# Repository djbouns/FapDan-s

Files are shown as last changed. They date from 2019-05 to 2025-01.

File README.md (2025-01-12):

# FapDan-s V2

## Le filtre à papier 100% DIY pour l'aquariophilie

Bonjour,

Ce filtre a papier 3D a été développé par Dan's avec ma colaboration.

#### Soutenir se projet par un DON, c'est nous permettre de vous proposez de nouveau projet, des évolutions et cela, toujours GRATUITEMENT.

 

### Pour la réalisation, il vous faudras :
- Du PETG : https://amzn.to/428bnMW,
  https://amzn.to/3FKoPeO,
  https://amzn.to/4ja6JEo,
  https://amzn.to/4gOcTZ9,
  https://amzn.to/3DQryoc
- Motoréducteur 3,5 ou 7 RPM en 12V : https://amzn.to/3Ugyaio
- Vis inox M3 *10mm : https://amzn.to/3wchOvQ
- Vis inox M3 *5mm : https://amzn.to/357KsCc
- Flotteur : https://amzn.to/4haH9gu
- Alimentation 12V 1A ou 2A : https://amzn.to/3Pyc8aK,
  https://amzn.to/4h7XCCi,
  https://amzn.to/2TbOJC2
- Arduino nano : https://amzn.to/40f2hLI (original),
  https://amzn.to/3Pw0kWr,
  https://amzn.to/3wakk5R,
  https://amzn.to/40f2kXU
- Shield arduino nano : https://amzn.to/3g7mm0U
- Relais : https://amzn.to/3vgb3ba,
  https://amzn.to/42dsw83
- bouton instantané : https://amzn.to/4gLURa3,
  https://amzn.to/3BT9tFx,
  https://amzn.to/4jeQeXx,
  https://amzn.to/4hcpkh8
- Lot leds + resistance : https://amzn.to/3C5HD8S
+ Ou
- Led seul : https://amzn.to/40fuBOa,
  https://amzn.to/40ag9Hq,
  https://amzn.to/3PvMlzX,
  https://amzn.to/3C55mpJ
- Resistance seul : https://amzn.to/42sKOT9,
  https://amzn.to/42f93UJ,
  https://amzn.to/3PssS3c,
  https://amzn.to/3PCEsbP

#### Fonctions :
> Temporisation du flotteur pour ne pas avoir de déclenchement du motoréducteur trop minime a répétition.  
> Led verte = système actif  
> Led rouge = système inactif  
> Le boitier active/désactive automatiquement le moteur en fonction du flotteur.  
> A la fin d'un rouleaux, cela génère des déclenchement répétitif du flotteur ou un trop long déclenchement, le boitier coupe le moteur / met le système inactif  
> Led verte allumé + flash de la led rouge = déclenchement répétitif survenu moins de 15 seconde après rotation du moteur ( le nombre de flash rouge correspondant au nombre de déclenchement intempestif consécutif, MAX 3 avant que le système soit mis inactif)  
> un appui sur le bouton supérieur a 1.5 seconde remet le système actif et met en marche le moteur. Lorsque vous relâcher le bouton, si le flotteur est bas, le moteur est coupé. Si le flotteur en haut, le moteur continue de tourner jusqu'au moment ou le flotteur soit en position basse.  

### tuto complet du montage :
- http://www.recifal-france.fr/fabrication-du-fapdan-s-v2-filtre-a-papier-de-a-a-z-t37701.html
### Vidéos de l'assemblage :
- https://www.youtube.com/watch?v=h5cT0cDPbm4
- https://www.youtube.com/watch?v=h5cT0cDPbm4
- https://www.youtube.com/shorts/dXKUHesqrk0

GRAND MERCI a Dan's pour ce filtre 3D

## Vous êtes FAN de DIY ? ... 
# Venez découvrir l'AQUABOUNS, 
## l'automate de gestion pour aquarium récifal
# www.aquabouns.fr

Téléchargement : https://github.com/djbouns

A bientôt

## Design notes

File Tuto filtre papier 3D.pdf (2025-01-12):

Bienvenu dans ce nouveau tuto DIY sur la fabrication du filtre à papier :

## Le FapDan's V2

Il y a plusieurs semaines, les plans 3D d'un filtre à papier ont été mis à disposition gratuitement sur un groupe Facebook, DIY RECIFAL 3D, (https://www.facebook.com/groups/318150642243111/) par Dan's (http://www.recifal-france.fr/membre8455.html)

Déjà très bien conçu au départ, j'ai pris contact avec Dan's en vue d'une collaboration pour améliorer encore plus ce filtre.
Après plusieurs semaines de test et d'évolution, nous pouvons dire aujourd'hui que le résultat est satisfaisant et que nous pouvons le partager.

Nous le mettons à dispositions cette nouvelle version, toujours GRATUITEMENT, accompagner de ce TUTO.

## Vous pouvez télécharger les plan 3d et le code ICI (https://github.com/djbouns/FapDan-s)

Ce tuto va se décomposer en plusieurs partie :
I. Cout
II. | Impression 3D des pièces
III. | Montage du filtre
IV. | Montage du boitier de commande (facultatif)
V. Fonctionnement du boitier de commande (facultatif)
VI. Trucs et astuces

Voici des liens pour le matériel nécessaire à la réalisation du FapDan’s :

| Du PETG : https://amzn.to/428bnMW , https://amzn.to/3FKoPeO ,
| https://amzn.to/4ja6JEo , https://amzn.to/4gOcTZ9 , https://amzn.to/3DQryoc
| Motoréducteur 3,5 RPM en 12V : https://amzn.to/3Ugyaio
| Vis inox M3 *10mm : https://amzn.to/3wchOvQ
| Vis inox M3 *5mm : https://amzn.to/357KsCc
| Flotteur : https://amzn.to/4haH9gu
| Alimentation 12V 1A ou 2A : https://amzn.to/3Pyc8aK , https://amzn.to/4h7XCCi ,
| https://amzn.to/2TbOJC2
| Arduino nano : https://amzn.to/40f2hLI (original), https://amzn.to/3Pw0kWr ,
| https://amzn.to/3wakk5R , https://amzn.to/40f2kXU
| Bouclier Arduino Nano : https://amzn.to/3g7mm0U
| Relais : https://amzn.to/3vgb3ba , https://amzn.to/42dsw83
| Bouton instantané : https://amzn.to/4gLURa3 , https://amzn.to/3BT9tFx ,
| https://amzn.to/4jeQeXx , https://amzn.to/4hcpkh8
| Lot de leds + résistances : https://amzn.to/3C5HD8S
| Led seul : https://amzn.to/40fuBOa , https://amzn.to/40ag9Hq ,
| https://amzn.to/3PvMlzX , https://amzn.to/3C55mpJ
| Résistance seule : https://amzn.to/42sKOT9 , https://amzn.to/42f93UJ ,
| https://amzn.to/3PssS3c , https://amzn.to/3PCEsbP

!!! ATTENTION !!!
Je ne suis pas électricien ni électronicien.
Ce qui suit n'est qu'un simple partage d'expérience. Toute connexion/interface avec des tensions dangereuses ne doit se faire que par du personnel qualifié et selon les normes en vigueur afin d'éviter tout risque d'accident ou d'incendie.
Djbouns décline toute responsabilité quant aux dommages directs ou indirects qui pourraient être causés.
I. Cout

Le cout de fabrication du filtre dépendra essentiellement du « petit matériel » déjà en votre possession (Leds, résistances, …)
Entre l’impression3D (environ 1kg de filament) et le reste de composant, le cout de fabrication est d’environ :
40€ / 70€ pour la version sans contrôleur
Et 65€ / 100€ Pour la version avec contrôleur

II. Impression 3D des pièces

Vous aurez besoin :
- Une imprimante 3D
- Une bobine de filament PETG

Je ne vais pas vous expliquer ici comment imprimer en 3D, d'autres tutoriels le ferons bien mieux que moi.
Je vous conseille d'avoir bien pris votre machine en main avant de vous lancer dans ces longues heures d'impressions.

Pour le filtre à papier et pour tout ce qui est en contact avec mon aquarium, j'utilise du filament en PETG car il résiste à l'eau et est homologué pour le contact alimentaire. En plus, le PETG est assez facile imprimer, lit a 80° et buse a 240° (chez moi)

Une fois toutes les pièces imprimées, vous pouvez passer à l’assemblage.

III. Assemblage du filtre

Vous aurez besoin :
- Des pièces imprimées en 3D
- D'un flotteur
- D'un motoréducteur
- Une alimentation 12Vdc (si vous n'utilisez pas le boitier de commande)

Dans un premier temps, il faut souder 2 fils à votre moteur.
Prévoyez une longueur plus on moins importante en fonction de votre montage (boitier de contrôle ou pas, distance de votre alimentation)

Ensuite, mise en place du moteur dans son logement :

Fixation avec les vis M3x10 INOX :

Mise en place du capot moteur :

Mise en place du rouleau moteur (il faut forcer un peu) :

Mise en place du cache (doit pouvoir se retirer pour mettre en place le papier) :

Pour recapituler ce montage, une petite vidéo

Regarder sur youtube.com (https://youtu.be/QKYtz0qKcmg)

On passe au montage complet du filtre : Regarder sur youtube.com (https://youtu.be/h5cT0cDPbm4)

Þ Si vous voulez réaliser le filtre à papier avec son boitier de commande, passer à l'étape III.

Þ Si vous ne souhaitez pas utiliser le boitier de commande, prenez connaissance des défauts que ce montage simplifier comporte :
- Pas de déclenchement manuel possible (il faut soulever le flotteur si on veut activer le moteur).
- Pas d'arrêt du moteur en fin de rouleau (soit le moteur va tirer jusque à ce que le papier se décolle du carton, soit le moteur va forcer et risque d'être endommager).
- Pas de temporisation (donc des micros déclenchement) dans le cas ou votre descente n'est pas régulière (syphon).

Pour le montage sans boitier de contrôle, Il va falloir brancher le flotteur, le motoréducteur et l'alimentation.
L'intérieur du compartiment moteur doit pouvoir vous permettre de faire les branchements pour qu’il soir ptoteger.
Si l'endroit vous parait trop petit, vous prouver aussi faire les connections à l’intérieur d’une petite boite de dérivation que vous installerez plus loin (protéger de l'eau)
Quoi qu'il en soit, les connexions à faire sont les mêmes, voici le schéma :

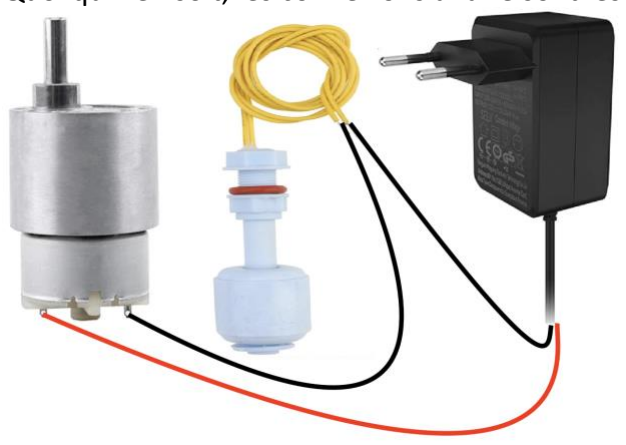
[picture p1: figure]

Avant de tout mettre en place, vérifier bien que le moteur tourne dans le bon sens. Dans le cas contraire inverser la polarité du moteur.
Maintenant, votre filtre est parfaitement fonctionnel !

IV. Montage du boitier de commande (facultatif)

Vous aurez besoin :

- Le boitier 3d
- D’un Arduino nano
- D’un relais ou mosfet
- D’une alimentation 12Vdc
- D’une LED verte + une LED rouge
- Deux résistances 1/2W, 1K
- D’un bouton instantané 12mm
- D’un domino / Wago, https://amzn.to/3C6jMpO, https://amzn.to/428foRC
- De gaine thermo rétractable, https://amzn.to/4gOgLJz, https://amzn.to/4gPaFJc
- De petits câble, https://amzn.to/40xrzq8, https://amzn.to/3PygcYG

Commencer par souder les LED aux résistances 1k et aux fils.
Si vous avez des doutes sur la façon de faire vous pouvez aller voir ici (https://www.interface-z.com/conseil/montage-led.php)

Souder 2 fils sur votre bouton

Installer les Leds et le bouton dans le boitier 3D :

Maintenez les Leds avec de la colle à chaud.

Fixer votre Shield et le relais ou Mosfet sur la plaque de la boite 3D :

Montage avec Relais | Montage avec Mosfet

Le Mosfet est préférable au relais car il ne comporte pas de composant en mouvement. De plus, si vous êtes susceptible coté bruit, vous n'aurez pas les clics du relais)
montage avec relais.

Afin de fiabiliser le montage, je vous conseille de souder les câbles sur les pin plutôt que d'utiliser des connexion femelle emboitable.

La suite du tuto sera faite en utilisant le Mosfet ( les connections du relais coté Arduino sont identique que le Mosfet)

Fixer 2 fils rouge sur un côté d’un domino.
Un de ces fil va jusqu’au Vin du Shield.
L’autre jusqu’au Vin du Mosfet.
Sur un autre domino fixer 2 fils noir:
Un de ces fil va jusqu’au GND du Shield (en même temps connecter sur le pin GND du Shield le GND le GND de votre alimentation 12V.
L’autre fil va jusqu’au GND du Mosfet.

Faite passer les fils de votre flotteur dans le boitier puis souder un des fils du flotteur avec un des fils du bouton + les GND des deux Leds (donc 4 fils reliés)

Connecter ces 4 fils sur le GND du Shield.
Connecter le positif de la LED verte (pin long) au Shield : D2 Connecter le positif de la LED rouge (pin long) au Shield : D3 Connecter le fil restant du flotteur au Shield : D4
Connecter le fil restant du bouton au Shield : D5

Votre montage doit ressembler à ça :

Connecter le fil venant du pin IN du Mosfet au Shield : A0
Passer le câble de votre alimentation dans le boitier puis connecter le positif au domino avec les fils rouges et le négatif sur le domino avec les fils noir (vérifier bien la polarité)
Votre montage doit ressembler à cela :

Il faut maintenant installer le programme dans votre Arduino nano.
Télécharger et installer l'IDE Arduino (https://www.arduino.cc/en/Main/Software)

Connecter votre Arduino nano en USB, le driver devrait s'installer automatiquement. Si ce n'est pas le cas, le driver se trouve dans C:\Program Files\Arduino\drivers Ouvrer "filtre_papier.ino" dans l'IDE Arduino
Aller dans outils / type de carte et sélectionner Arduino nano
Dans outils / port, sélectionner le port de votre Arduino (exemple, COM1) Vous pouvez cliquer sur téléverser le programme.

Si le téléversement est très long et fini par une erreur, il est possible que votre carte ais un "vieux" bootloader. Dans ce cas, faite cette modification, outils / processeur et sélectionner ATmega328p (old bootloader) puis recommencer le téléversement

Votre Arduino est programmé.

Installer le sur le Shield

Maintenant, votre filtre est parfaitement fonctionnel !

Avant de le mettre en place, vérifier bien que le moteur tourne dans le bon sens de rotation. Dans le cas contraire inverser la polarité du moteur.

Fermer le boitier et mettez les 4 vis sur les côtés

V. Fonctionnement du boitier de commande (facultatif)
1. LED verte = système actif
2. LED rouge = système inactif
3. Le boitier active/désactive automatiquement le moteur en fonction du flotteur.
4. Temporisation du flotteur pour ne pas avoir de déclenchement du motoréducteur trop minime à répétition.
5. A la fin d’un rouleau, cela génère des déclenchements répétitifs du flotteur ou un trop long déclenchement, le boitier coupe le moteur / met le système inactif.
6. LED verte allumé + flash de la LED rouge = déclenchement répétitif survenu moins de 15 secondes après rotation du moteur (le nombre de flash rouge correspondant au nombre de déclenchement intempestif consécutif, MAX 3 avant que le système soit mis inactif)
7. Un appui sur le bouton supérieur à 1.5 seconde remet le système actif et met en marche le moteur. Lorsque vous relâcher le bouton, si le flotteur est bas, le moteur est coupé. Si le flotteur en haut, le moteur continue de tourner jusqu'au moment où le flotteur soit en position basse.

VI. Trucs et astuces

1. Déclenchement du flotteur :
Nos bac sont tous diffèrent et l'eau qui arrive dans le filtre peut se comporter de façon totalement différente.
Cela peut générer des réactions "bizarres" du flotteur, déclenchement saccader (siphon de la descente), pas de déclenchement (l'eau en rotation retombe par-dessus le flotteur, cette force empêche le flotteur de monter).
Pour contrer cela plusieurs solutions qu'ils vous faudra tester et peut être combiner.
- Orienter le tuyau d'arrivée d'eau du filtre de différente façon, vers le haut, le bas etc.
- Utiliser une des 2 protections de flotteur fournie dans les plan 3D.
(exemple chez moi sans protection flotteur, tuyau vers le haut = flotteur ne se déclenchait pas. Solution, tuyau vers le bas + protection flotteur)
2. Les consommable :
Au prix des rouleaux de papier et pour notre planète, sa fait chi** de les jeter.
Le papier peut être lavé !
- Tremper le 24h dans l'eau de javel puis un tour a la machine à laver à froid sans autre produit, on fait sécher et c’est reparti.
- Le papier est difficile à faire tenir sur le rouleau moteur et le rouleau papier lavé. Pour solutionner le problème vous aller avoir besoin de fil et d'une aiguille.
Prenez une extrémité de papier et replier la d'un centimètre 3 fois.
Ensuite vous faite une couture sur le milieu de ce pli sur toute la longueur :

Faite cela sur les 2 extrémités du papier.
- Pour fixer le papier sur les rouleaux il suffit de glisser la couture dans la fente des rouleaux. Le "Rouleau papier lave V2.STL" est spécialement conçu pour que vous puissiez enrouler vos papiers laver dessus.

- Enrouler le papier sur le rouleau.
Il est inutile de serrer fort le papier sur le rouleau !
Si le rouleau de papier propre est trop serré, il oppose une résistance et le moteur va serrer le papier en l'enroulant coté sale. Cela va rendre votre changement de rouleau très difficile).
3. Changement de rouleau :
- Lorsque votre rouleau est fini, retirez le rouleau vide et débloquer le papier. Fixer le nouveau papier a l'ancien avec une aiguille ou un cure-dent puis tirer sur l'ancien papier coté moteur jusqu'à ce que le nouveau papier soit du côté moteur.
- Débloquer le rouleau du moteur, enlever le cache de côté et retirer l'ancien papier fixer le nouveau papier

J’espère que ce tuto vous a été utile, Bon montage à tous Et un GRAND MERCI à Dan's

## WWW.AQUABOUNS.FR

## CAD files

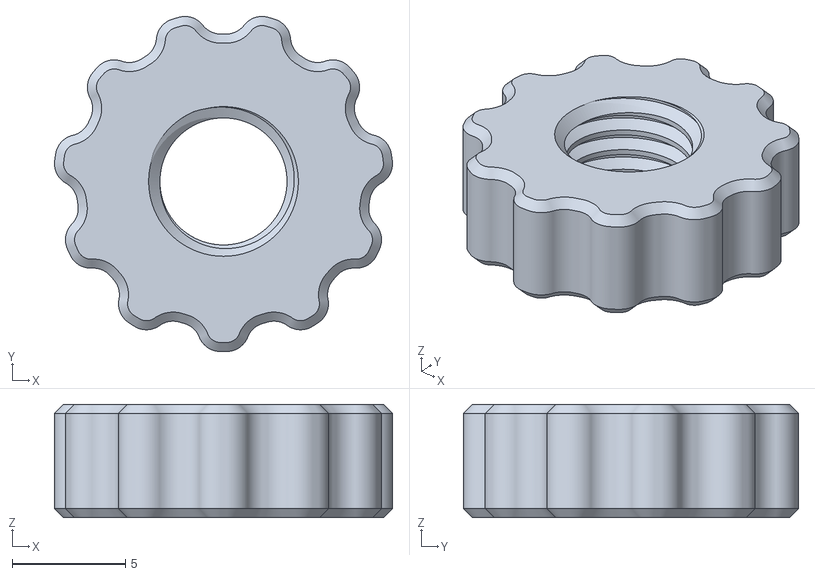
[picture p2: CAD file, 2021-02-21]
Plan 3D/Ecrou assemblage M6.STL
14.9 x 14.8 x 5.00

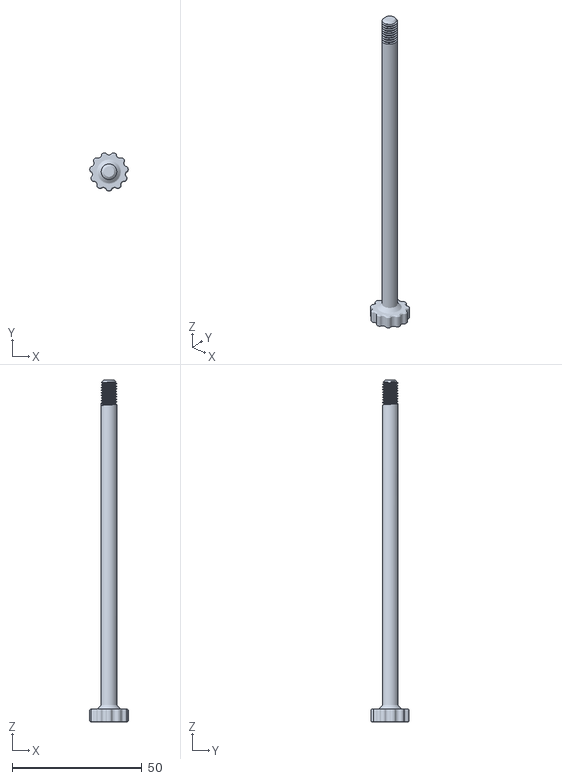
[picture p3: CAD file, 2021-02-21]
Plan 3D/Vis assemblage M6.STL
14.9 x 14.8 x 132.0

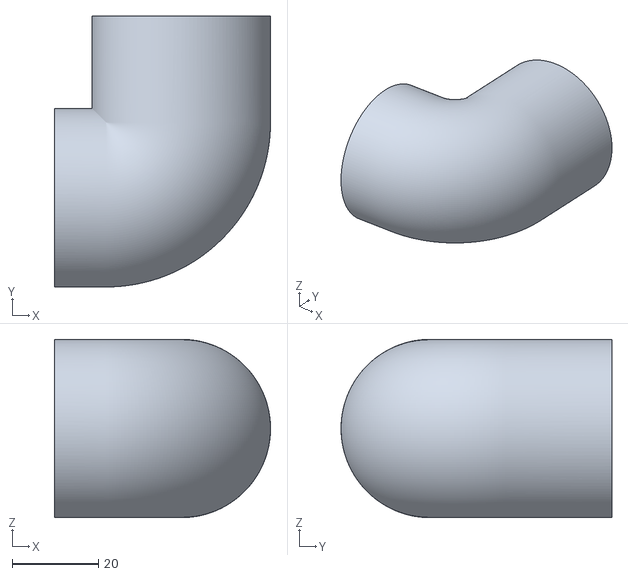
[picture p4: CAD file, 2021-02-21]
Plan 3D/Coude 90 V2 (32mm).STL
50.0 x 62.7 x 41.3

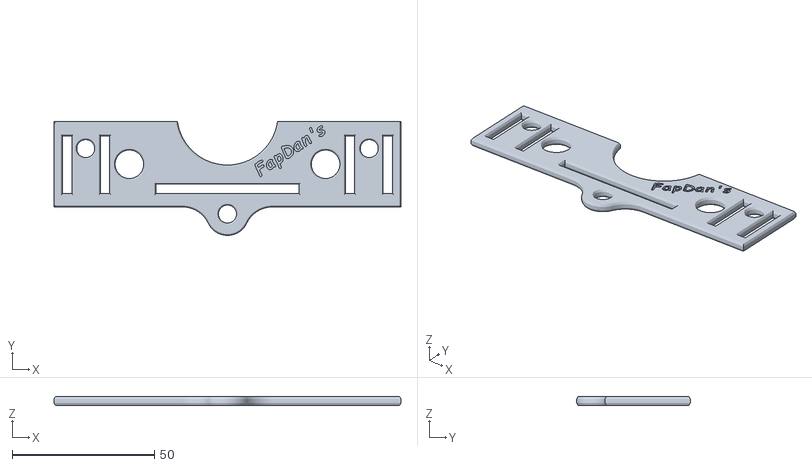
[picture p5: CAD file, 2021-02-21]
Plan 3D/Piece C.STL
122.0 x 40.0 x 3.00

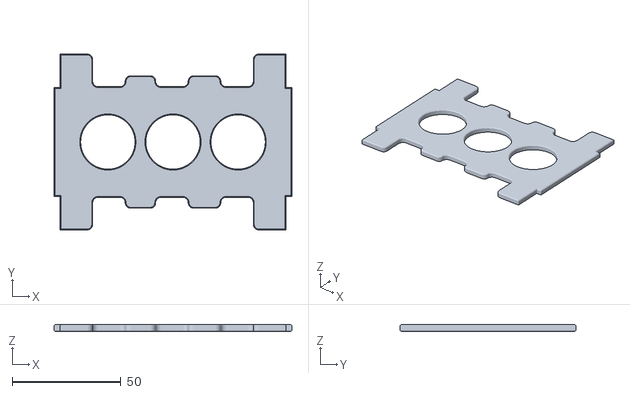
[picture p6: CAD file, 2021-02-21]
Plan 3D/Grille B.STL
109.6 x 81.0 x 3.00

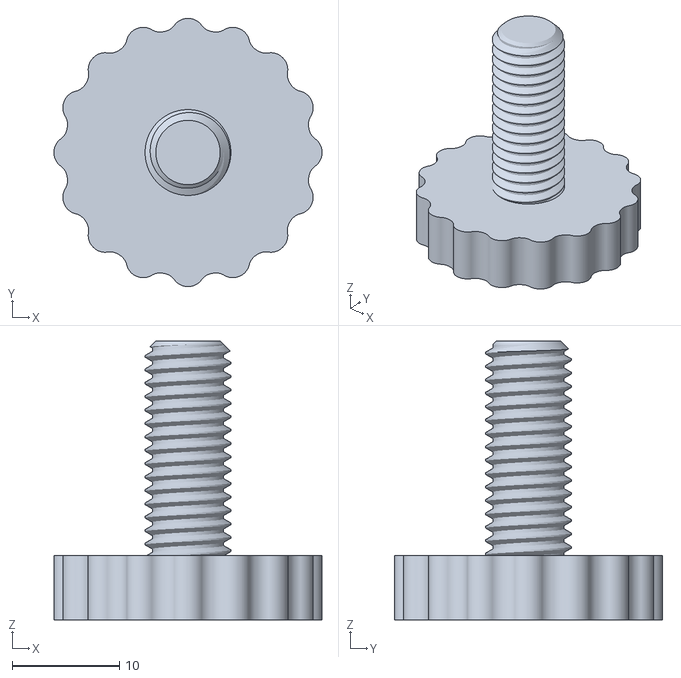
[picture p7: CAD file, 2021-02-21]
Plan 3D/Vis rouleaux M8.STL
25.0 x 25.0 x 26.0

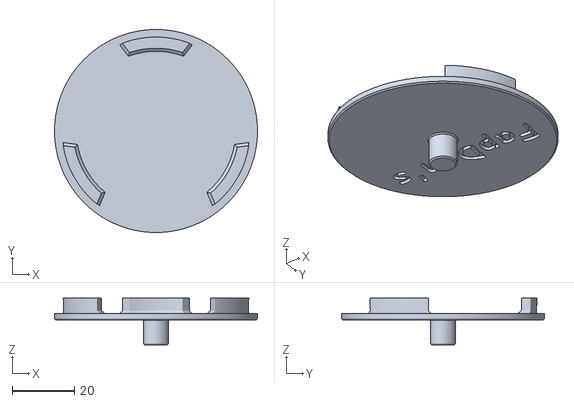
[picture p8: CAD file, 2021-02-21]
Plan 3D/Bouchon rouleau moteur V2.STL
65.0 x 65.0 x 15.0

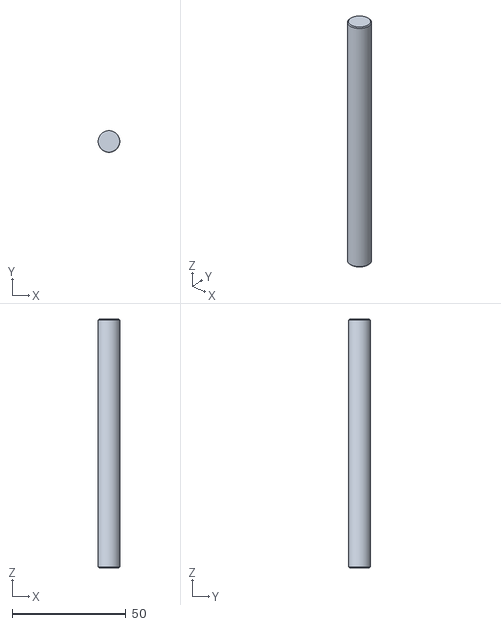
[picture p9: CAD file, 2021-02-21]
Plan 3D/Rouleau retour.STL
9.53 x 9.53 x 109.5

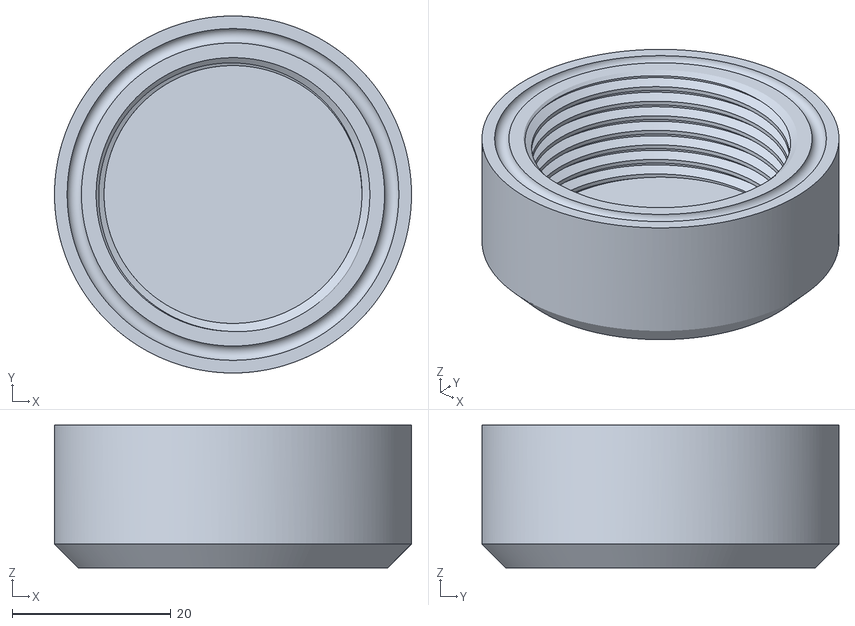
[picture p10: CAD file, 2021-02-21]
Plan 3D/Bouchon.STL
45.0 x 45.0 x 18.0

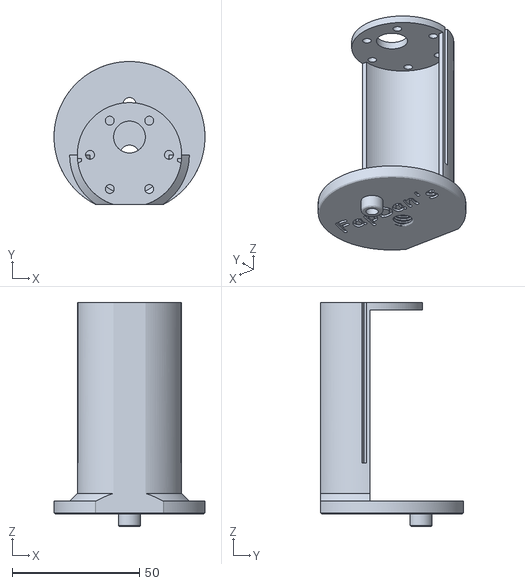
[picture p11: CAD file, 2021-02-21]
Plan 3D/Support moteur.STL
59.3 x 56.1 x 88.0

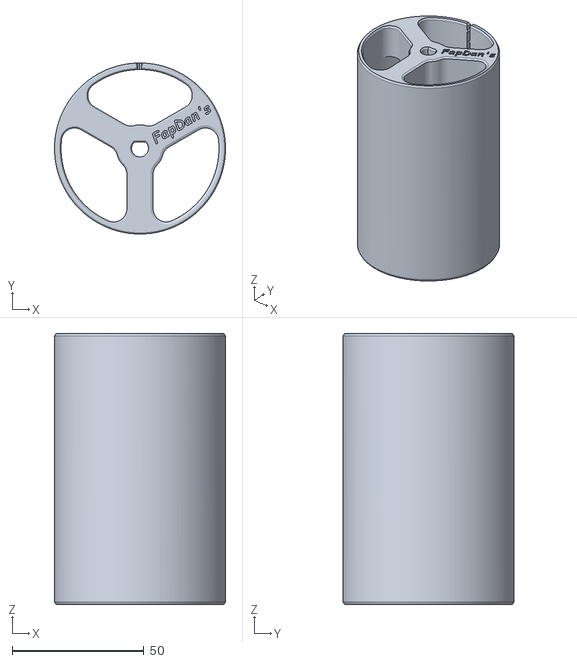
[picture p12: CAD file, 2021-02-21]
Plan 3D/Rouleau moteur V3.STL
65.0 x 65.0 x 103.0

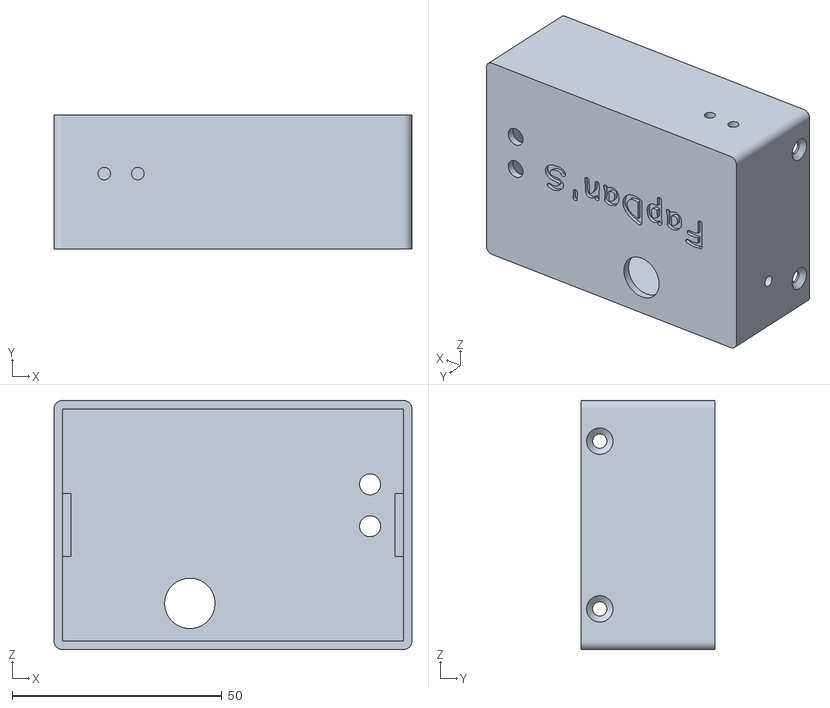
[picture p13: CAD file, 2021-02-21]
Plan 3D/Couvercle controleur.STL
85.4 x 32.0 x 59.4

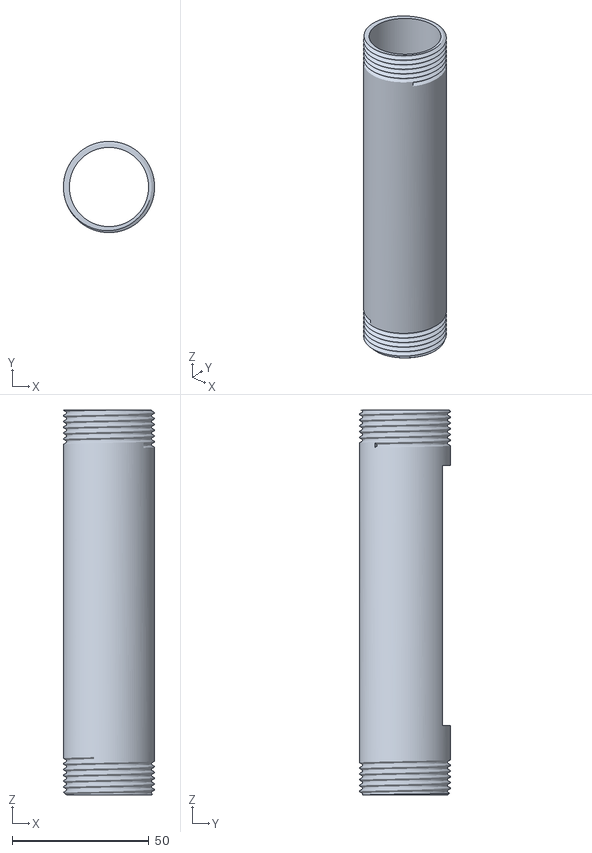
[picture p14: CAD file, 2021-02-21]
Plan 3D/Tuyau V2.STL
33.4 x 33.4 x 141.0

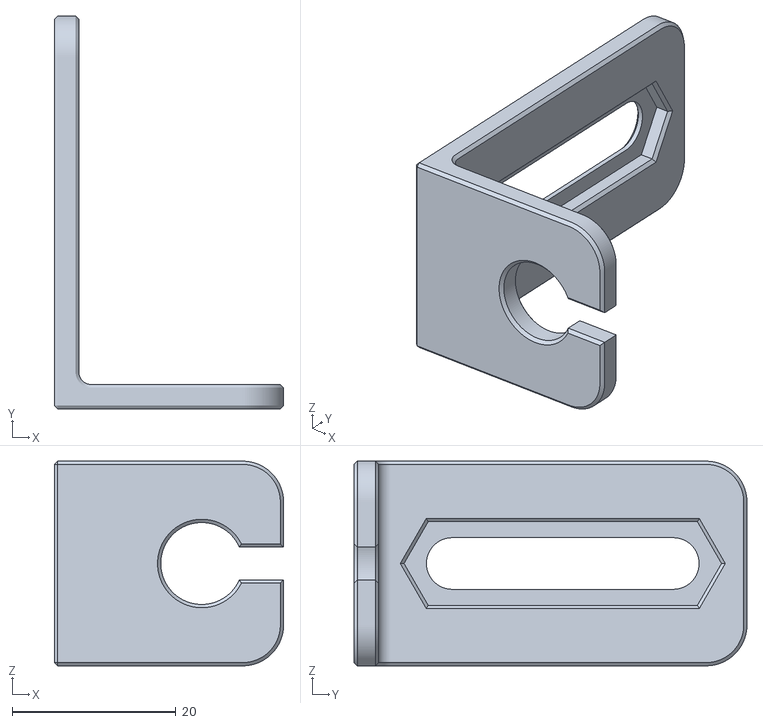
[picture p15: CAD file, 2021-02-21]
Plan 3D/Support niveau V2.STL
28.0 x 48.0 x 25.0

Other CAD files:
Plan 3D/Coude 90 V2 (USA).STL
Plan 3D/Piece B.STL
Plan 3D/Piece D haut auto V3.STL
Plan 3D/Base controleur.STL
Plan 3D/Centre rouleau papier lave V2.STL
Plan 3D/Couvercle moteur.STL
Plan 3D/Ecrou support capteur niveau M6.STL
Plan 3D/Grille A.STL
Plan 3D/Piece A bas.STL
Plan 3D/Piece A haut auto V2.STL
Plan 3D/Protecteur flotteur V2.STL
Plan 3D/Protecteur flotteur.STL
Plan 3D/Rouleau papier lave V2.STL
Plan 3D/Rouleau papier neuf.STL
Plan 3D/Support.STL
Plan 3D/Vis rouleaux M6.STL
Plan 3D/Vis support capteur niveau M6.STL

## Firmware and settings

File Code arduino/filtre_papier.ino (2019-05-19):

/********************************************************************************************************************************************************************************************************
****                                                                                          FapDan's v2.0                                                                                          ****
****                                                                                       écrit par Djbouns                                                                                         ****
****                                                   Gestion du FapDan's, filtre a papier réalisé en impression 3D avec les plans dessinés par Dan's                                               ****
****                                                                                           18/05/2019                                                                                            ****
********************************************************************************************************************************************************************************************************/

/* FapDan's, Gestion du filtre a papier réalisé en impression 3D avec les plans dessinés par Dan's
   Copyright (C) 2019 par dj bouns

   Ce programme est un logiciel libre: vous pouvez le redistribuer
   et/ou le modifier selon les termes de la "GNU General Public
   License", tels que publiés par la "Free Software Foundation"; soit
   la version 2 de cette licence ou (à votre choix) toute version
   ultérieure.

   Ce programme est distribué dans l'espoir qu'il sera utile, mais
   SANS AUCUNE GARANTIE, ni explicite ni implicite; sans même les
   garanties de commercialisation ou d'adaptation dans un but spécifique.

   Se référer à la "GNU General Public License" pour plus de détails.
   Vous la trouverez dans l'onglet GNU_General_Public_License.h

   Vous devriez avoir reçu une copie de la "GNU General Public License"
   en même temps que ce programme; sinon, écrivez a la "Free Software
   Foundation, Inc., 675 Mass Ave, Cambridge, MA 02139, USA".*/

#include <avr/wdt.h>

//$$$$$$$$$$$$$$$$$$$$$$$$$$$$$$$$$$$$$$$$$$$$$$$$$$$$$$$$$$$$$$$$$$$$$$$$$$$$$$$$$$$$$$$$$$$ Déclarations $$$$$$$$$$$$$$$$$$$$$$$$$$$$$$$$$$$$$$$$$$$$$$$$$$$$$$$$$$$$$$$$$$$$$$$$$$$$$$$$$$$$$$$$$$$
const byte relais = A0; // pin du relais
const byte ledVerte = 2; // pin de la led verte
const byte ledRouge = 3; // pin de la led rouge
const byte flotteur = 4; // pin du flotteur
const byte bouton = 5; // pin du bouton
const uint16_t delaisFlotteurHaut = 500; // delais avant mise en route du moteur 1/2 sec
const uint16_t delaismoteurOn = 1000; // delais avant mise en route du moteur 1/2 sec
const uint16_t delaisMaxFlotteurHaut = delaisFlotteurHaut + 3500; // delais max avant de stoper moteur 3.5 sec + delais flotteur haut
uint32_t compteurFlotteur = 0; // pour stocker le compteur flotteur
boolean compteurFlotteurOn = false; // pour mettre on off le compteur flotteur
boolean enFonction = true; // pour mettre on off le moteur
const uint16_t delaisBouton = 1500; // delais dactivation du bouton 1.5 sec
const uint16_t delaisFinDeRlx = 15000; // delais durant le quel les declanchement son comptés , pour detécter la fin de rouleau 15 sec
const uint8_t declenchementMaxFinDeRlx = 3; // 3 declenchements
uint8_t declenchementRlx =  0; // pour stocker les declenchements
uint32_t compteurDeclenchement = 0; // pour stocker le compteur declenchement
uint32_t compteurBouton = 0; // pour stocker le compteur bouton
boolean compteurBoutonOn = false; // pour mettre on off le compteur bouton

//$$$$$$$$$$$$$$$$$$$$$$$$$$$$$$$$$$$$$$$$$$$$$$$$$$$$$$$$$$$$$$$$$$$$$$$$$$$$$$$$$$$$$$$$$$$ Debug $$$$$$$$$$$$$$$$$$$$$$$$$$$$$$$$$$$$$$$$$$$$$$$$$$$$$$$$$$$$$$$$$$$$$$$$$$$$$$$$$$$$$$$$$$$
//#define DEBUG // à commenter pour enlever le debug
#ifdef DEBUG
#define DebugPrintLN(x)  {Serial.println(x);}
#else
#define DebugPrintLN(x)
#endif

//$$$$$$$$$$$$$$$$$$$$$$$$$$$$$$$$$$$$$$$$$$$$$$$$$$$$$$$$$$$$$$$$$$$$$$$$$$$$$$$$$$$$$$$$$$$ Setup $$$$$$$$$$$$$$$$$$$$$$$$$$$$$$$$$$$$$$$$$$$$$$$$$$$$$$$$$$$$$$$$$$$$$$$$$$$$$$$$$$$$$$$$$$
void setup() {
  Serial.begin(9600);
  pinMode(ledRouge, OUTPUT); // configure le pin en sortie
  pinMode(ledVerte, OUTPUT); // configure le pin en sortie
  pinMode(relais, OUTPUT); // configure le pin en sortie
  pinMode(flotteur, INPUT_PULLUP); // configure le pin en entre en mode pullup
  pinMode(bouton, INPUT_PULLUP); // configure le pin en entre en mode pullup
  digitalWrite(ledVerte, HIGH); // led verte on
  wdt_enable(WDTO_8S); // Si plus de remise a zero du compteur "reboot" (fait dans le loop) au bout de 8 secondes = bug de l'arduino = reboot automatique !
}

//$$$$$$$$$$$$$$$$$$$$$$$$$$$$$$$$$$$$$$$$$$$$$$$$$$$$$$$$$$$$$$$$$$$$$$$$$$$$$$$$$$$$$$$$$$$ Loop $$$$$$$$$$$$$$$$$$$$$$$$$$$$$$$$$$$$$$$$$$$$$$$$$$$$$$$$$$$$$$$$$$$$$$$$$$$$$$$$$$$$$$$$$$$
void loop() {
  if (digitalRead (bouton) == LOW) { // si bouton active
    DebugPrintLN("bouton appuyer"); // debug
    if (compteurBoutonOn == false) { // si compteur bouton off
      compteurBoutonOn = true; // compteur bouton on
      compteurBouton = millis(); // stock le timer
      DebugPrintLN("démarre le compteur du bouton"); // debug
    }
    if (delaisBouton < (millis() - compteurBouton)) { // si bouton active plus longtemps que delaisBouton
      enFonction = true; // moteur on
      digitalWrite(ledVerte, HIGH); // led verte on
      digitalWrite(ledRouge, LOW); // led rouge off
      digitalWrite(relais, HIGH); // relais on = moteur on
      declenchementRlx = 0; // remet le compteur de declenchement a zero
      compteurFlotteurOn = false; // remet le compteur flotteur en OFF
      DebugPrintLN("réactive le fonctionnement, LED verte et rouleau ON manuelement"); // debug
      while (digitalRead (flotteur) == LOW) { // boucle temps que le flotteur n'est pas bas
      }
    }
  }
  else { // si bouton pas active
    compteurBoutonOn = false; // compteur off
    if (enFonction == true) { // si en fonction
      DebugPrintLN("systeme activé, LED verte"); // debug
      if (digitalRead (flotteur) == LOW) { // si flotteur haut
        DebugPrintLN("flotteur Haut"); // debug
        if (compteurFlotteurOn == false) { // si compteur off
          compteurFlotteurOn = true; // on met le compteur on
          compteurFlotteur = millis(); // stock le timer      
          DebugPrintLN("démarre le compteur de flotteur haut"); // debug
        }
        if (millis() - compteurDeclenchement < delaisFinDeRlx) { // si le flotteur est de nouveau en position haute pendant
          declenchementRlx++; // incremente le compteur de declenchement
          for (uint8_t cligonote = 0; cligonote < declenchementRlx; cligonote++) {
            digitalWrite(ledRouge, HIGH); // led rouge on
            delay(250);
            digitalWrite(ledRouge, LOW); // led rouge off
            delay(1000);
          }
        }
        else {
          declenchementRlx = 0; // remet le compteur de declenchement a zero
        }
        if (delaisMaxFlotteurHaut < millis() - compteurFlotteur || declenchementRlx >= declenchementMaxFinDeRlx) { // si flotteur declencher plus longtemps que le delaismaxflotteurhaut873
          digitalWrite(relais, LOW); // relais off
          digitalWrite(ledRouge, HIGH); // led rouge on
          digitalWrite(ledVerte, LOW); // led verte off
          enFonction = false; // on desactive
          DebugPrintLN("fin de rouleaux / trop de declenchement consecutif, SYSTEM DESACTIVE, LED rouge ON"); // debug
        }
        else if (delaisFlotteurHaut < millis() - compteurFlotteur ) { // si flotteur declencher plus longtemps que delaisflotteurhaut
          digitalWrite(relais, HIGH); // relais on = moteur on
          compteurDeclenchement = millis(); // stock le timer
          DebugPrintLN("le rouleau tourne"); // debug
        }
      }
      else { // sinon (flotteur bas)
        if (compteurFlotteurOn) { // si compteur est ON
          delay (delaismoteurOn); // delay pour que le moteur tourne encore unpeu apres la remise en bas du flotteur
        }
        digitalWrite(relais, LOW); // relais off
        digitalWrite(ledRouge, LOW); // led rouge off
        digitalWrite(ledVerte, HIGH); // led verte on
        compteurFlotteurOn = false; // compteur off
        DebugPrintLN("flotteur bas, rouleau Off et LED verte"); // debug
      }
    }
    else {
      digitalWrite(relais, LOW); // relais off
      digitalWrite(ledRouge, HIGH); // led rouge off
      DebugPrintLN("systeme desactivé, LED rouge"); // debug
    }
  }
  wdt_reset(); // indique que le loop est OK, pas de bug, remise a zero du compteur "reboot" du watchdog

#ifdef DEBUG // si debug actif
  delay(500); // delais pour lire debug plus facilement
#endif
}

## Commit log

2025-01-12 Code Arduino
2025-01-12 Rename Axe rouleau.STL to Plan 3D/Axe rouleau.STL
    [Axe rouleau.STL]
